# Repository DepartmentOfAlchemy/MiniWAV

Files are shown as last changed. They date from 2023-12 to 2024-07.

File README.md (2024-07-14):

# MiniWAV

The MiniWAV is a [FeatherWing](https://learn.adafruit.com/adafruit-feather/featherwings) designed for the [Feather](https://learn.adafruit.com/adafruit-feather) ecosystem create by [Adafruit](https://www.adafruit.com). It provides an SD card reader and I2S audio output to an 1/8" jack stereo audio line output. The board is designed to be used in a haunted attraction prop control system.

## Pinout
- I2S
  - BCK: A0
  - LRCK: A1
  - DIN: A2
- SD Card SPI
  - SCLK: SCK
  - DI: MO
  - DO: MI
  - CS: D10
  - DAT2: D9
  - DAT1: D6
  - CARDDET: D5

### SD Card
| Feather Pin | SPI | SDIO |
|---|---|---|
| SCK | SCLK | CLK |
| MO | SI | CMD |
| MI | SO | D0 |
| D10 | CS | D3 |
| D9 | DAT2 | D2 |
| D6 | DAT1 | D1 |
| D5 | CARDDET | CARDDET |

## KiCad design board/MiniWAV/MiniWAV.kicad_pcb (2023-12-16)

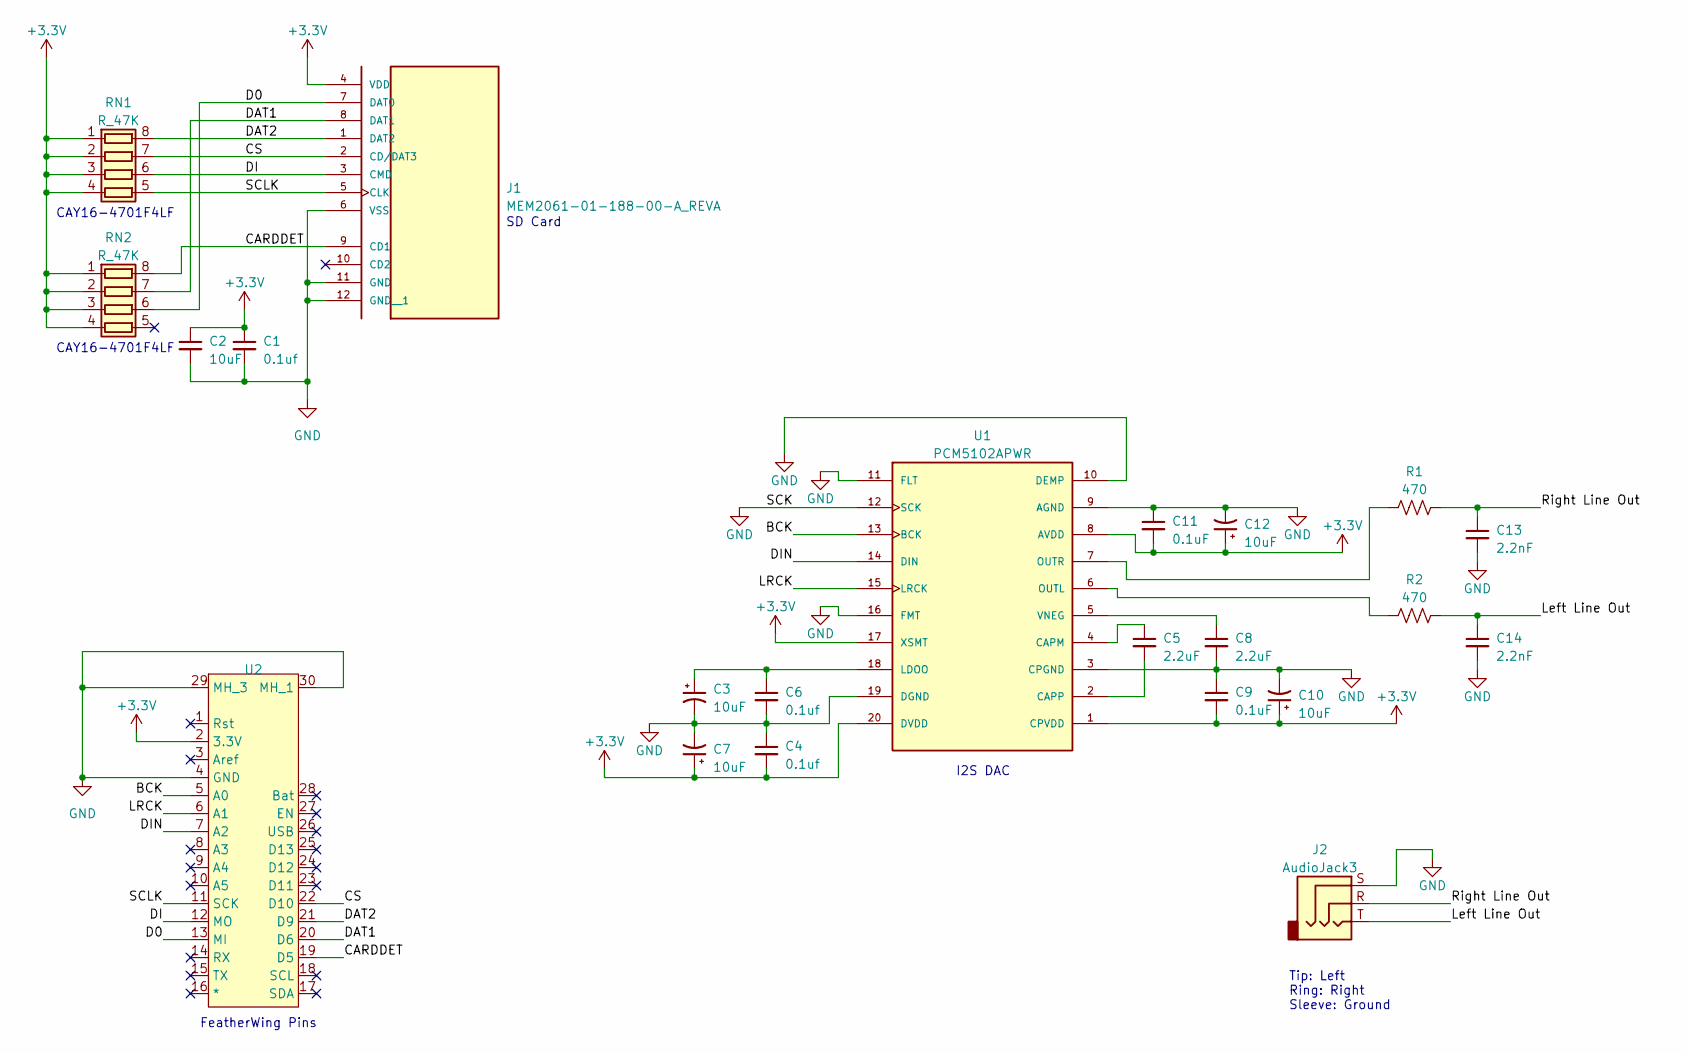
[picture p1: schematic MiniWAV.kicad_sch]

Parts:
C1, C4, C6: 0.1uf; C_0603_1608Metric
C2: 10uF; C_0603_1608Metric
C3, C7, C10, C12: 10uF; CAPPM2012X120N
C5, C8: 2.2uF; C_0603_1608Metric
C9, C11: 0.1uF; C_0603_1608Metric
C13, C14: 2.2nF; C_0603_1608Metric
J1: MEM2061-01-188-00-A_REVA; GCT_MEM2061-01-188-00-A_REVA
J2: AudioJack3; Jack_3.5mm_CUI_SJ-3523-SMT_Horizontal
R1, R2: 470; R_0603_1608Metric
RN1, RN2: R_47K; R_Array_Convex_4x0603
U1: PCM5102APWR; SOP65P640X120-20N; PARTREV C
U2: Feather Pins

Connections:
+3.3V: C1.1, C2.1, C4.2, C7.1, C9.2, C10.1, C11.2, C12.1, J1.4 (VDD), RN1.1 (R1.1), RN1.2 (R2.1), RN1.3 (R3.1), RN1.4 (R4.1), RN2.1 (R1.1), RN2.2 (R2.1), RN2.3 (R3.1), RN2.4 (R4.1), U1.1 (CPVDD), U1.8 (AVDD), U1.17 (XSMT), U1.20 (DVDD), U2.2 (3.3V)
/BCK: U1.13 (BCK), U2.5 (A0)
/CARDDET: J1.9 (CD1), RN2.8 (R1.2), U2.19 (D5)
/CS: J1.2 (CD/DAT3), RN1.7 (R2.2), U2.22 (D10)
/D0: J1.7 (DAT0), RN2.6 (R3.2), U2.13 (MI)
/DAT1: J1.8 (DAT1), RN2.7 (R2.2), U2.20 (D6)
/DAT2: J1.1 (DAT2), RN1.8 (R1.2), U2.21 (D9)
/DI: J1.3 (CMD), RN1.6 (R3.2), U2.12 (MO)
/DIN: U1.14 (DIN), U2.7 (A2)
/LRCK: U1.15 (LRCK), U2.6 (A1)
/Left Line Out: C14.1, J2.T, R2.2
/Right Line Out: C13.1, J2.R, R1.2
/SCLK: J1.5 (CLK), RN1.5 (R4.2), U2.11 (SCK)
GND: C1.2, C2.2, C3.2, C4.1, C6.2, C7.2, C8.2, C9.1, C10.2, C11.1, C12.2, C13.2, C14.2, J1.6 (VSS), J1.11 (GND), J1.12 (GND__1), J2.S, U1.3 (CPGND), U1.9 (AGND), U1.10 (DEMP), U1.11 (FLT), U1.12 (SCK), U1.16 (FMT), U1.19 (DGND), U2.4 (GND), U2.29 (MH_3), U2.30 (MH_1)
unnamed: C5.1, U1.4 (CAPM)
unnamed: C5.2, U1.2 (CAPP)
unnamed: C3.1, C6.1, U1.18 (LDOO)
unnamed: R2.1, U1.6 (OUTL)
unnamed: R1.1, U1.7 (OUTR)
unnamed: C8.1, U1.5 (VNEG)

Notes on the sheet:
SD Card
I2S DAC
FeatherWing Pins
CAY16-4701F4LF
Tip: Left Ring: Right Sleeve: Ground

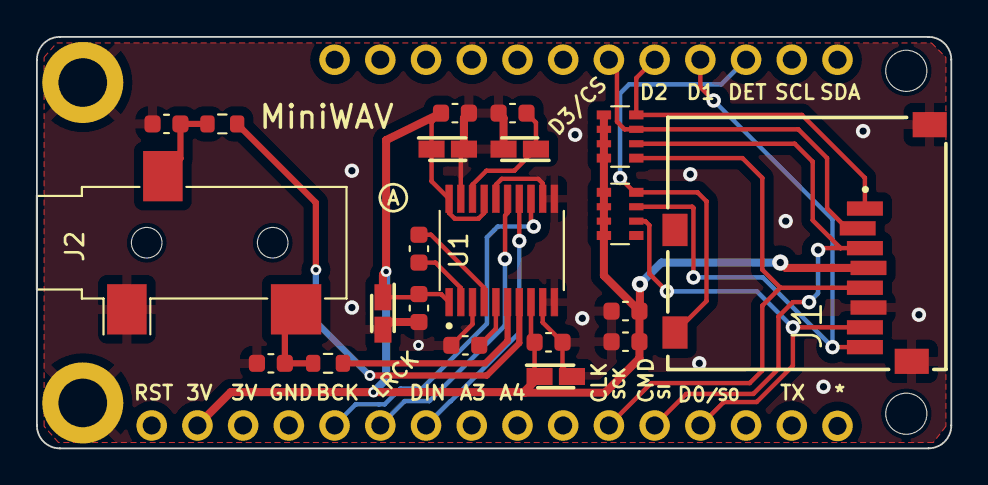
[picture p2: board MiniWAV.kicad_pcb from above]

Board: 2 copper layers, 50.8 x 22.9 mm, 22 parts (0 on the bottom side), 20 nets.

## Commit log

2023-12-16 Initial commit.
    [MiniWAV-B_Cu.gbl, MiniWAV-B_Mask.gbs, MiniWAV-B_Paste.gbp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]
2023-12-16 Update README.md
    Basic description of the board and pinout.
2024-07-14 Added the SD Card table to list both SPI and SDIO pins
